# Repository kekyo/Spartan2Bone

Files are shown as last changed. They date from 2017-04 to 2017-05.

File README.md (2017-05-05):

# Spartan2Bone

## What is this?

* This is prototyping board for Xilinx Spartan-II FPGA processor.
* These circuit mostly simple and easy usage, exclude any test devices.

## Features

* This board include features:
  * [Xilinx XC2S30 Spartan-II FPGA processor](https://www.xilinx.com/support/documentation/data_sheets/ds001.pdf)
  * [Xilinx XCF01S 1Mbit configuration flash ROM](https://www.xilinx.com/support/documentation/user_guides/ug161.pdf)
  * I/O header (IO[1..28], I_GCK[0..3], D[0..7], IRDY[1..2], TRDY[1..2], /WRITE, /CS, BUSY, INIT)
  * JTAG header
  * Mode jumper
  * 3.3V regulator and power configuration jumper

## Why Spartan-II now?

* Xilinx Spartan-II FPGA family already deprecated, these processors too old. But Spartan-II has "3.3V operation and 5V torelant I/Os."
* That means, easy usage for "Prototyping by breadboard or likely environments."
* We can get Spartan-II some market (ex: DigiKey). (2017 May)
* Another fit usages, we can use Xilinx XC95 CPLD series. This processors too old and NOT deprecated, but too few macro cells/registers. If you are interesting XC95, [try to my project PGA44DIP44](https://github.com/kekyo/PGA44DIP44).

TODO:

## Pre render output

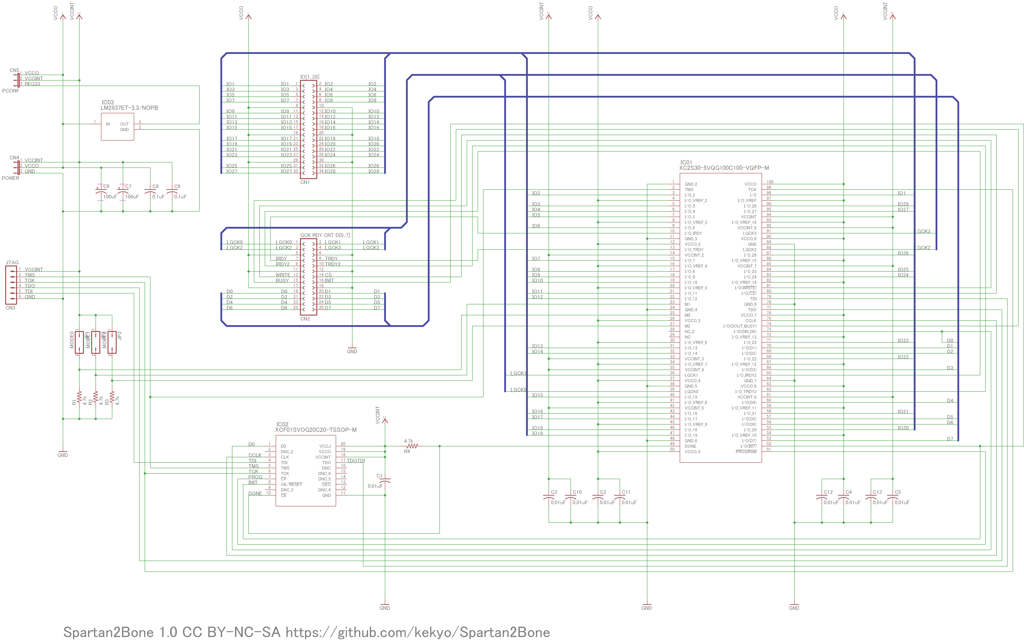
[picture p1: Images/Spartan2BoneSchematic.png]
Spartan2Bone schematic

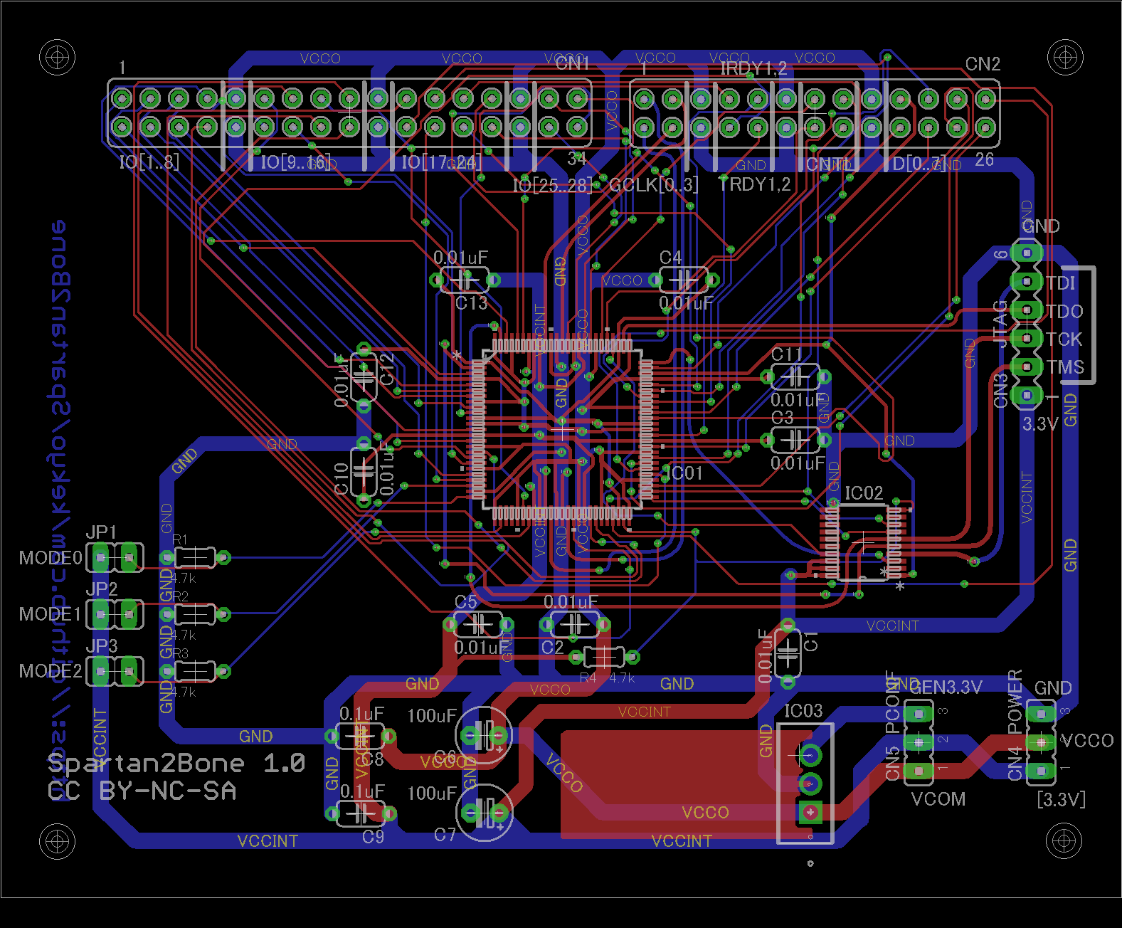
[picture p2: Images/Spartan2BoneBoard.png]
Spartan2Bone board design


## How to create Spartan2Bone

* Order and get Spartan2Bone PCB.

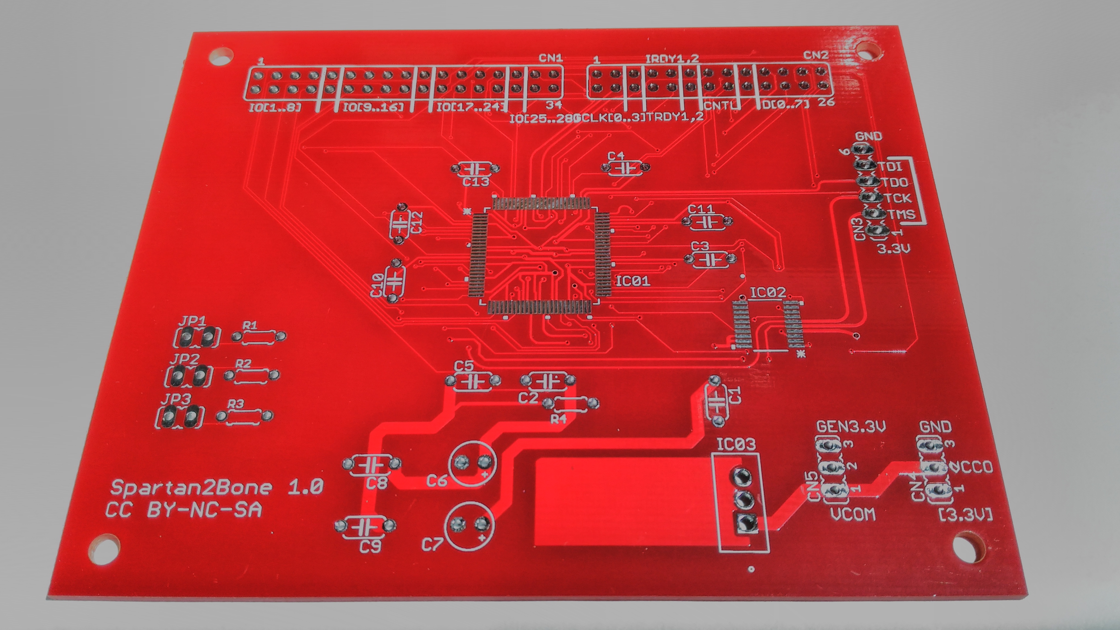
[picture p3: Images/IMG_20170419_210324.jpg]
Spartan2Bone PCB


* Order and get required parts (TODO: parts list)

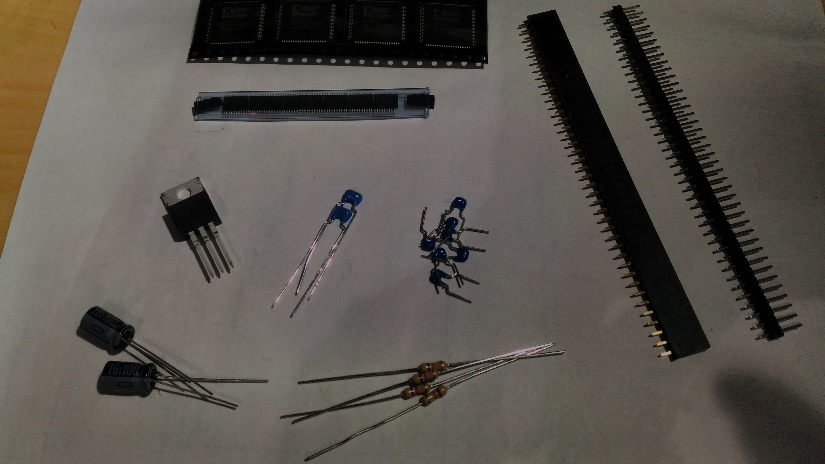
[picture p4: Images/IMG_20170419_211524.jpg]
Spartan2Bone parts (TODO: parts list)


* Solder Spartan-II
  * Caution!! You must looks direction for Spartan-II! If you missed, repair too hard.

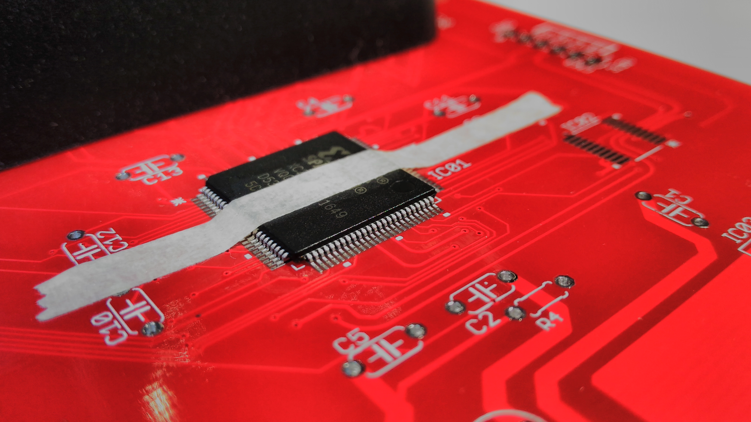
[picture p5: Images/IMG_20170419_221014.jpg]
Solder Spartan-II (Use 3M Scotch 230 Drafting Tape)

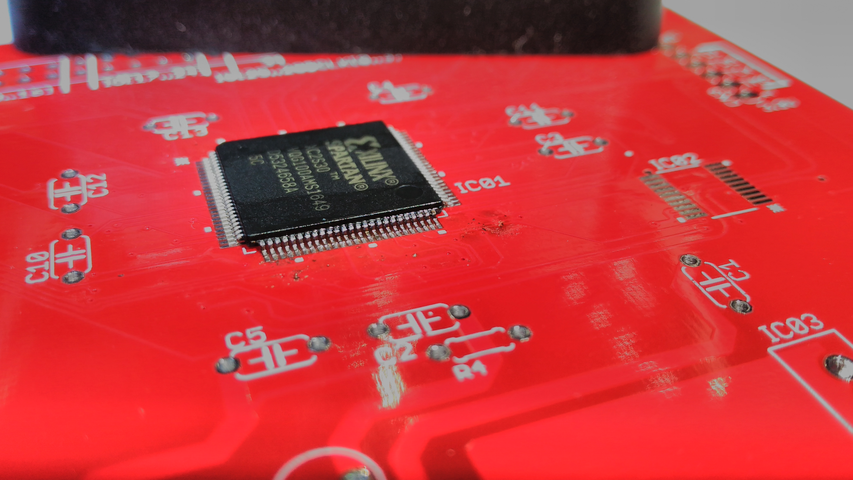
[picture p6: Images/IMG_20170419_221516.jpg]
Solder Spartan-II (Use Flux)


* Solder configuration flash ROM
  * Caution direction too.

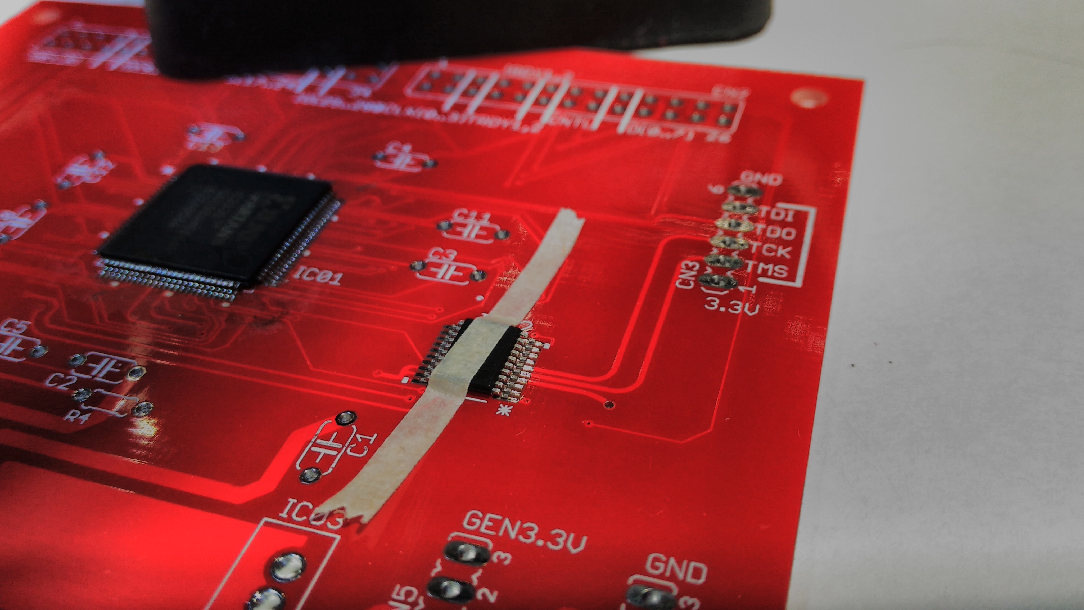
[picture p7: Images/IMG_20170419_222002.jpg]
Solder configuration flash ROM (Use 3M Scotch 230 Drafting Tape)

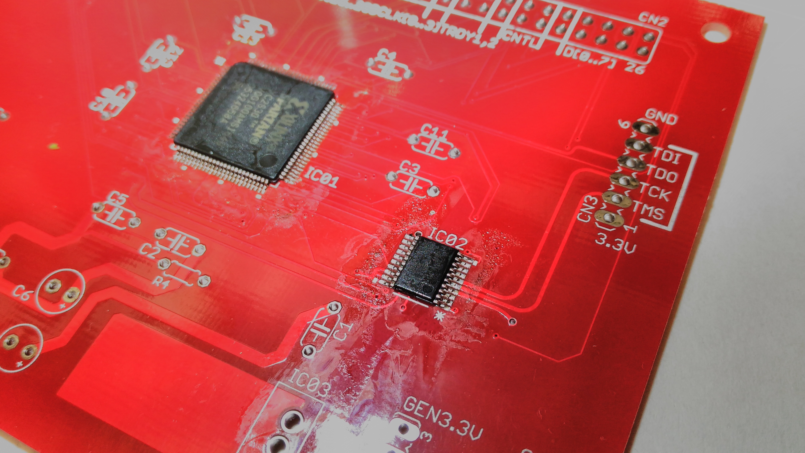
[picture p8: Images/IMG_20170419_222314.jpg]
Solder configuration flash ROM (Use Flux)


* Cleaning by Flux remover.

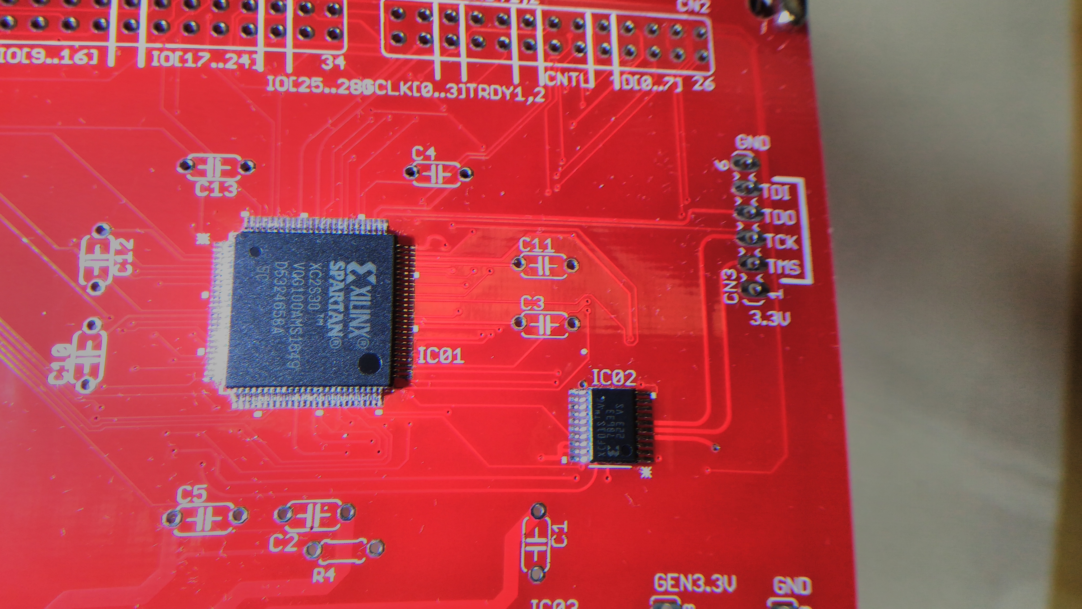
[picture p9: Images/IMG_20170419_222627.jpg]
Results


* Solder other parts.

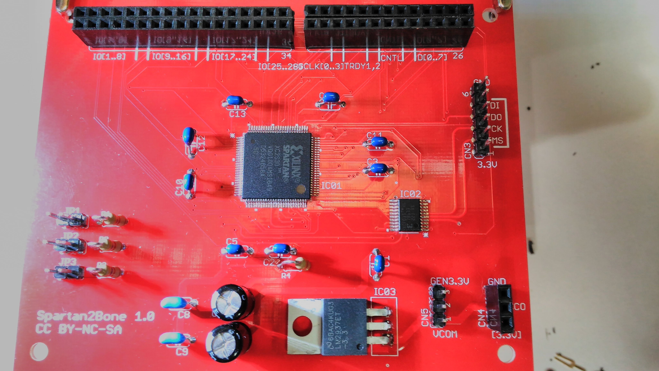
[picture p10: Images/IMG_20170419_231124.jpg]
Final results


## Sample codes

### LedBrink

* [Sample for simple LED brink code. (Require Xilinx ISE 10.1)](LedBrink/)

Sample for simple LED brink.

### FizzBuzz

* [Sample for FizzBuzz by VerilogHDL. Output by 7seg LED and two Fizz-Buzz LEDs. (Require Xilinx ISE 10.1)](FizzBuzz/)

Sample for FizzBuzz.

## LICENSE

* Schematic, artwork and documents: [Under CC BY-NC-SA 4.0](https://creativecommons.org/licenses/by-nc-sa/4.0/)
* Code: [Apache V2](https://www.apache.org/licenses/LICENSE-2.0)

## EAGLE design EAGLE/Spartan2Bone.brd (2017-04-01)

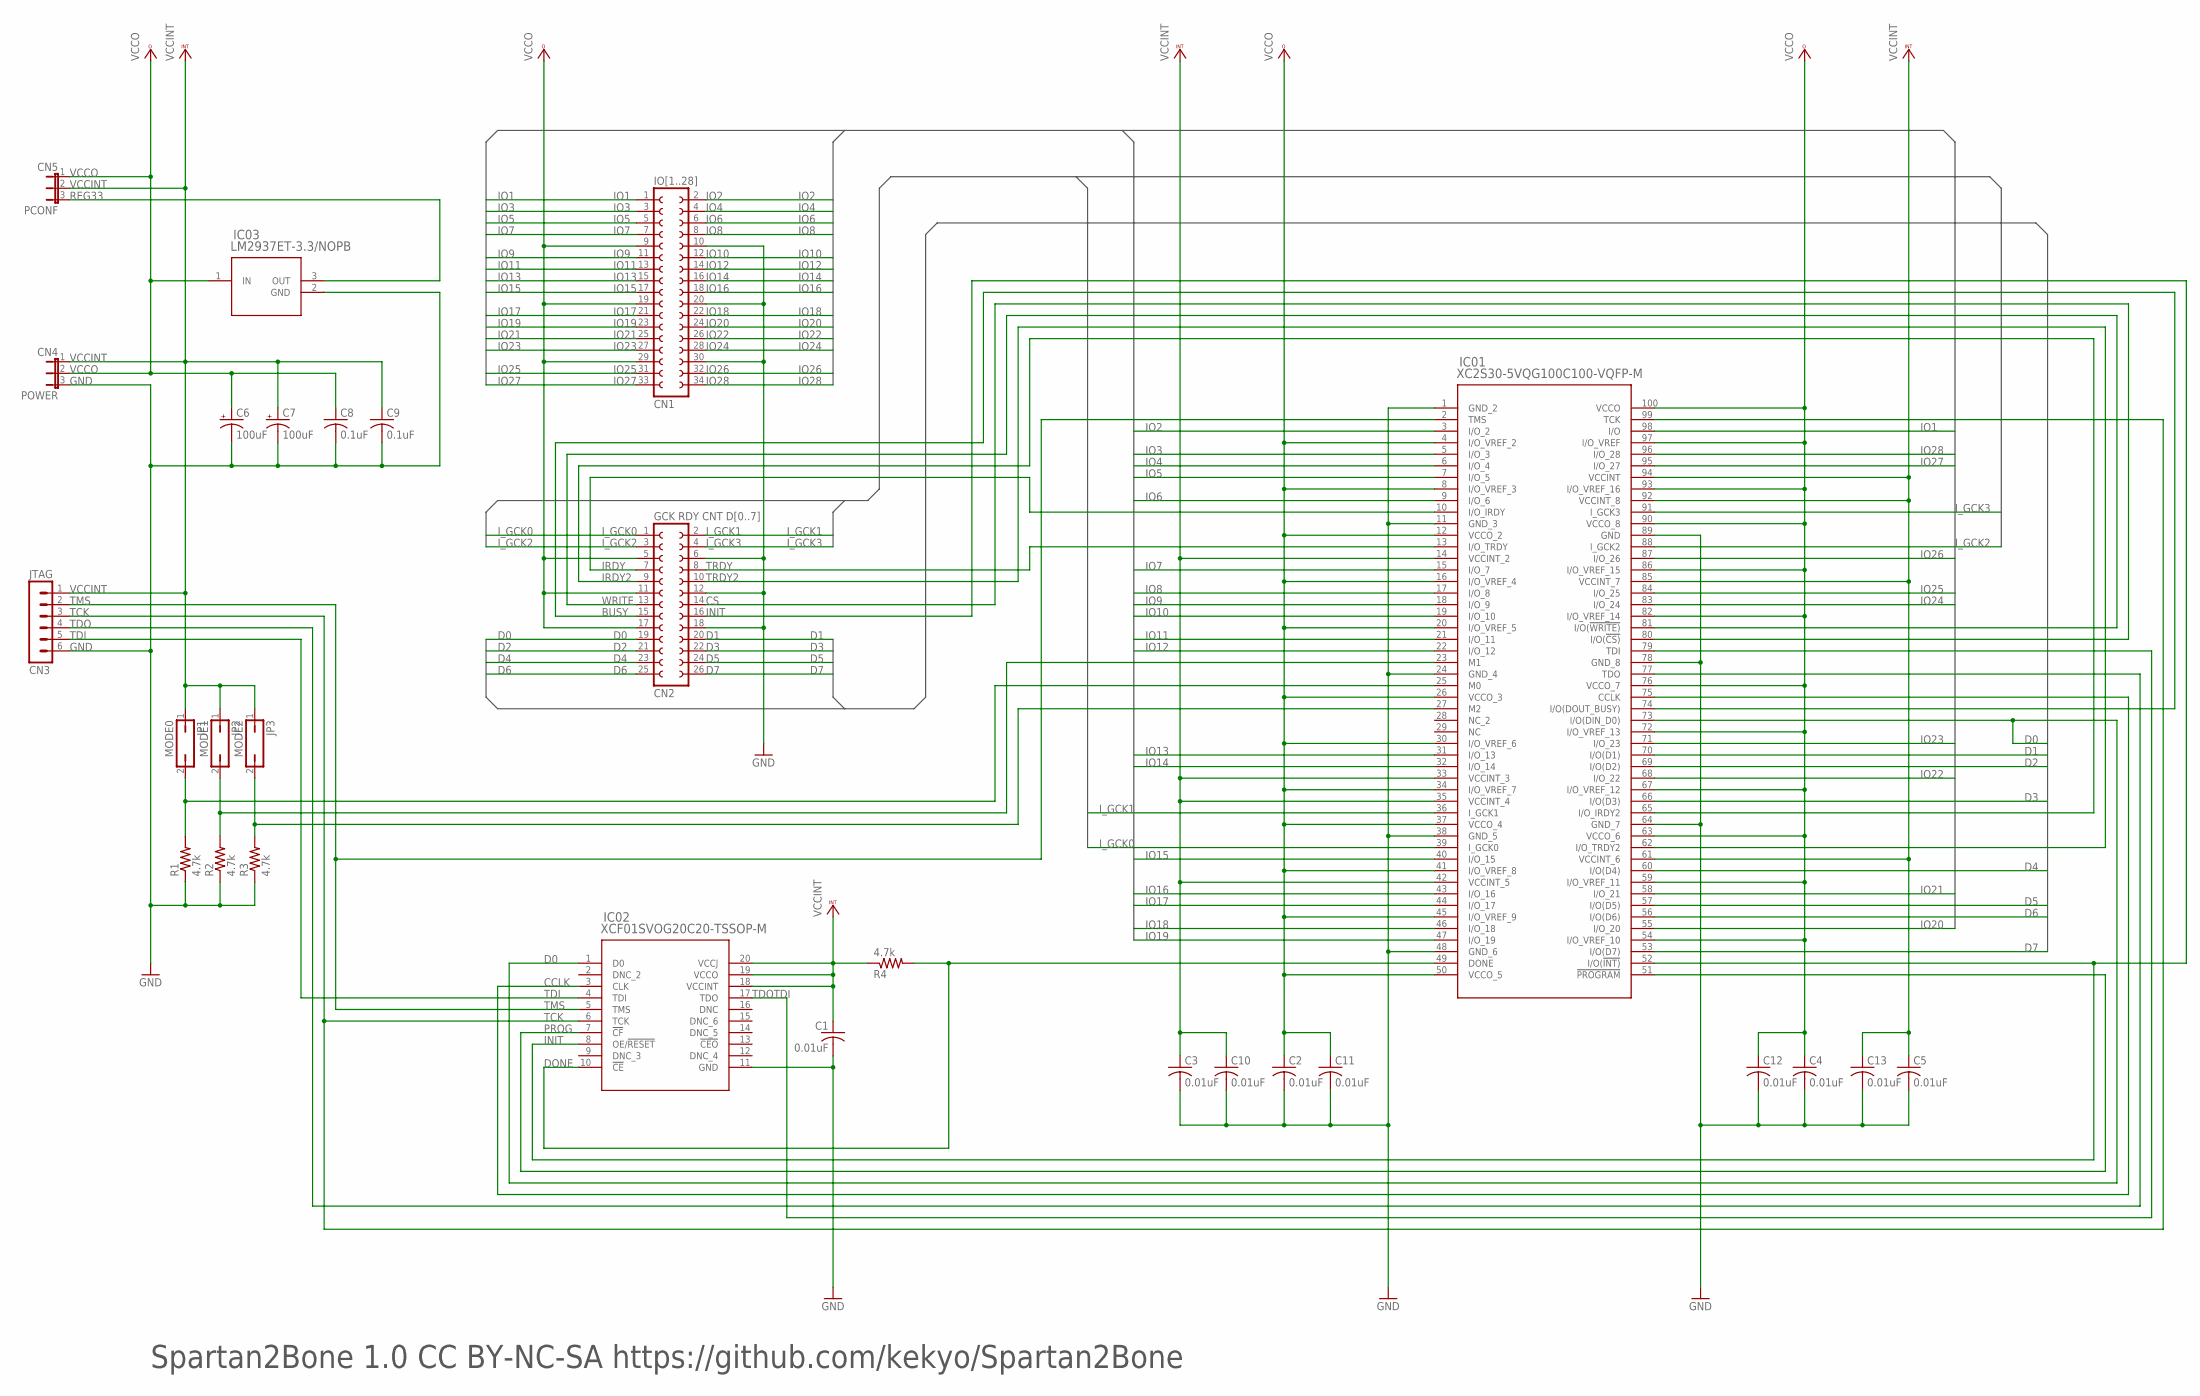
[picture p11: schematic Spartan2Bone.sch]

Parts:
C1, C2, C3, C4, C5, C10, C11, C12, C13: 0.01uF; C050-024X044
C6, C7: 100uF; E2,5-5
C8, C9: 0.1uF; C050-024X044
CN1: IO[1..28]; FE17-2
CN2: GCK RDY CNT D[0..7]; FE13-2
CN3: JTAG; MA06-1
CN4: POWER; JP2
CN5: PCONF; JP2
IC01: XC2S30-5VQG100C100-VQFP-M; 100-VQFP-M
IC02: XCF01SVOG20C20-TSSOP-M; 20-TSSOP-M
IC03: LM2937ET-3.3/NOPB; T03B
JP1: MODE0; JP1
JP2: MODE1; JP1
JP3: MODE2; JP1
R1, R2, R3, R4: 4.7k; 0204/5

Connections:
BUSY: CN2.15, IC01.74 (I/O(DOUT_BUSY))
CCLK: IC01.75 (CCLK), IC02.3 (CLK)
CS: CN2.14, IC01.80 (I/O(!CS))
D0: CN2.19, IC01.73 (I/O(DIN_D0)), IC02.1 (D0)
D1: CN2.20, IC01.70 (I/O(D1))
D2: CN2.21, IC01.69 (I/O(D2))
D3: CN2.22, IC01.66 (I/O(D3))
D4: CN2.23, IC01.60 (I/O(D4))
D5: CN2.24, IC01.57 (I/O(D5))
D6: CN2.25, IC01.56 (I/O(D6))
D7: CN2.26, IC01.53 (I/O(D7))
DONE: IC01.49 (DONE), IC02.10 (!CE), R4.2
GND: C1.2, C2.2, C3.2, C4.2, C5.2, C6.-, C7.-, C8.2, C9.2, C10.2, C11.2, C12.2, C13.2, CN1.10, CN1.20, CN1.30, CN2.6, CN2.12, CN2.18, CN3.6, CN4.3, IC01.1 (GND_2), IC01.11 (GND_3), IC01.24 (GND_4), IC01.38 (GND_5), IC01.48 (GND_6), IC01.64 (GND_7), IC01.78 (GND_8), IC01.89 (GND), IC02.11 (GND), IC03.2 (GND), R1.1, R2.1, R3.1
INIT: CN2.16, IC01.52 (I/O(!INT)), IC02.8 (OE/!RESET)
IO1: CN1.1, IC01.98 (I/O)
IO2: CN1.2, IC01.3 (I/O_2)
IO3: CN1.3, IC01.5 (I/O_3)
IO4: CN1.4, IC01.6 (I/O_4)
IO5: CN1.5, IC01.7 (I/O_5)
IO6: CN1.6, IC01.9 (I/O_6)
IO7: CN1.7, IC01.15 (I/O_7)
IO8: CN1.8, IC01.17 (I/O_8)
IO9: CN1.11, IC01.18 (I/O_9)
IO10: CN1.12, IC01.19 (I/O_10)
IO11: CN1.13, IC01.21 (I/O_11)
IO12: CN1.14, IC01.22 (I/O_12)
IO13: CN1.15, IC01.31 (I/O_13)
IO14: CN1.16, IC01.32 (I/O_14)
IO15: CN1.17, IC01.40 (I/O_15)
IO16: CN1.18, IC01.43 (I/O_16)
IO17: CN1.21, IC01.44 (I/O_17)
IO18: CN1.22, IC01.46 (I/O_18)
IO19: CN1.23, IC01.47 (I/O_19)
IO20: CN1.24, IC01.55 (I/O_20)
IO21: CN1.25, IC01.58 (I/O_21)
IO22: CN1.26, IC01.68 (I/O_22)
IO23: CN1.27, IC01.71 (I/O_23)
IO24: CN1.28, IC01.83 (I/O_24)
IO25: CN1.31, IC01.84 (I/O_25)
IO26: CN1.32, IC01.87 (I/O_26)
IO27: CN1.33, IC01.95 (I/O_27)
IO28: CN1.34, IC01.96 (I/O_28)
IRDY: CN2.7, IC01.10 (I/O_IRDY)
IRDY2: CN2.9, IC01.65 (I/O_IRDY2)
I_GCK0: CN2.1, IC01.39 (I_GCK0)
I_GCK1: CN2.2, IC01.36 (I_GCK1)
I_GCK2: CN2.3, IC01.88 (I_GCK2)
I_GCK3: CN2.4, IC01.91 (I_GCK3)
M0: IC01.25 (M0), JP1.2, R1.2
M1: IC01.23 (M1), JP2.2, R2.2
M2: IC01.27 (M2), JP3.2, R3.2
PROG: IC01.51 (!PROGRAM), IC02.7 (!CF)
REG33: CN5.3, IC03.3 (OUT)
TCK: CN3.3, IC01.99 (TCK), IC02.6 (TCK)
TDI: CN3.5, IC02.4 (TDI)
TDO: CN3.4, IC01.77 (TDO)
TDOTDI: IC01.79 (TDI), IC02.17 (TDO)
TMS: CN3.2, IC01.2 (TMS), IC02.5 (TMS)
TRDY: CN2.8, IC01.13 (I/O_TRDY)
TRDY2: CN2.10, IC01.62 (I/O_TRDY2)
VCCINT: C1.1, C3.1, C5.1, C7.+, C9.1, C10.1, C13.1, CN3.1, CN4.1, CN5.2, IC01.14 (VCCINT_2), IC01.33 (VCCINT_3), IC01.35 (VCCINT_4), IC01.42 (VCCINT_5), IC01.61 (VCCINT_6), IC01.85 (VCCINT_7), IC01.92 (VCCINT_8), IC01.94 (VCCINT), IC02.18 (VCCINT), IC02.19 (VCCO), IC02.20 (VCCJ), JP1.1, JP2.1, JP3.1, R4.1
VCCO: C2.1, C4.1, C6.+, C8.1, C11.1, C12.1, CN1.9, CN1.19, CN1.29, CN2.5, CN2.11, CN2.17, CN4.2, CN5.1, IC01.4 (I/O_VREF_2), IC01.8 (I/O_VREF_3), IC01.12 (VCCO_2), IC01.16 (I/O_VREF_4), IC01.20 (I/O_VREF_5), IC01.26 (VCCO_3), IC01.30 (I/O_VREF_6), IC01.34 (I/O_VREF_7), IC01.37 (VCCO_4), IC01.41 (I/O_VREF_8), IC01.45 (I/O_VREF_9), IC01.50 (VCCO_5), IC01.54 (I/O_VREF_10), IC01.59 (I/O_VREF_11), IC01.63 (VCCO_6), IC01.67 (I/O_VREF_12), IC01.72 (I/O_VREF_13), IC01.76 (VCCO_7), IC01.82 (I/O_VREF_14), IC01.86 (I/O_VREF_15), IC01.90 (VCCO_8), IC01.93 (I/O_VREF_16), IC01.97 (I/O_VREF), IC01.100 (VCCO), IC03.1 (IN)
WRITE: CN2.13, IC01.81 (I/O(!WRITE))

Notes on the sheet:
Spartan2Bone 1.0 CC BY-NC-SA https://github.com/kekyo/Spartan2Bone

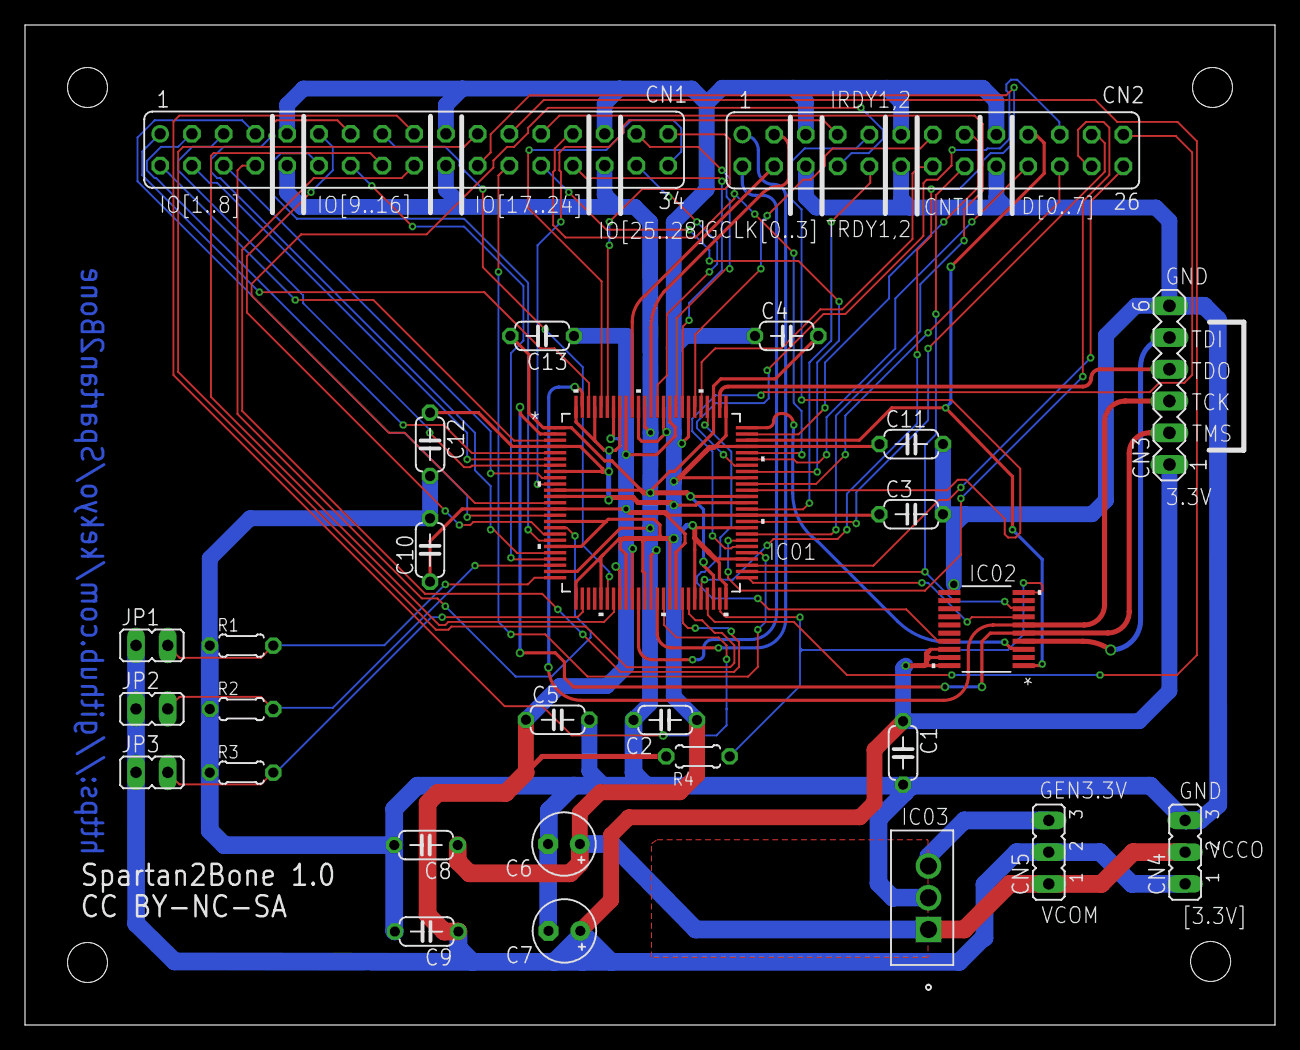
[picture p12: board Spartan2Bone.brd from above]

Board: 2 copper layers, 100.0 x 80.0 mm, 28 parts (0 on the bottom side), 63 nets.

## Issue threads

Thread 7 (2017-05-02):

Rearrange R-T-L.

kekyo, 2017-05-02:
Platform cable USB II cable connect from left side to right, so Spartan2Bone board always reversed up-to-down side. Bit poor.

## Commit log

2017-03-30 Initial commit.
    [Spartan2Bone.sch]
2017-03-30 Add labels.
    [Spartan2Bone.sch]
2017-03-30 Fixed ERC.
    [Spartan2Bone.sch]
2017-03-31 Partial implement board design.
    [Spartan2Bone.brd, Spartan2Bone.sch]
2017-04-01 Fixed board design.
    [Spartan2Bone.brd, Spartan2Bone.sch]
2017-04-01 Add gerver files.
    [Spartan2Bone.GBL, Spartan2Bone.GBO, Spartan2Bone.GBP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]
2017-04-22 EAGLE related files move to folder.
    [Spartan2Bone.GBL, Spartan2Bone.GBO, Spartan2Bone.GBP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]
2017-05-02 First time LED brink tested.
2017-05-04 Add fizzbuzz sample.
2017-05-05 * Add code header. * Add soldering images.
2017-05-05 Add sample video.
